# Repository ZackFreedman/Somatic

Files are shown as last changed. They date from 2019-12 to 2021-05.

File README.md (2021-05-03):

# Somatic
The Somatic is a wearable keyboard and mouse. It translates hand signs and motions into action, like the somatic component of a spell in Dungeons and Dragons.

See the project in action at https://www.youtube.com/watch?v=6raRftH9yxM!

**This project is defunct!!** The EM7180SFP is no longer in production, and I can't put any more effort into this project to design around it. Consider this a starting point only!

The Somatic project's priorities are:
* Control any wearable computer with a heads-up display
* Ready to use all day, instantly, with no Internet
* Doesn't cause fatigue or interfere with other tasks
* Fast enough to do a quick search in less than 10 seconds

The Somatic does not:
* Reproduce your hand in 3-D space
* Let you type on a virtual keyboard
* Use any cloud services at all

The project is still in a pretty rough state. If I revisit the project, the priorities are:
* Lay out and fab circuit board
* Make case smaller
* Replace on/off Hall sensors with continuous sensors

The Somatic project is MIT licensed, copyright 2019 Zack Freedman and Voidstar Lab.

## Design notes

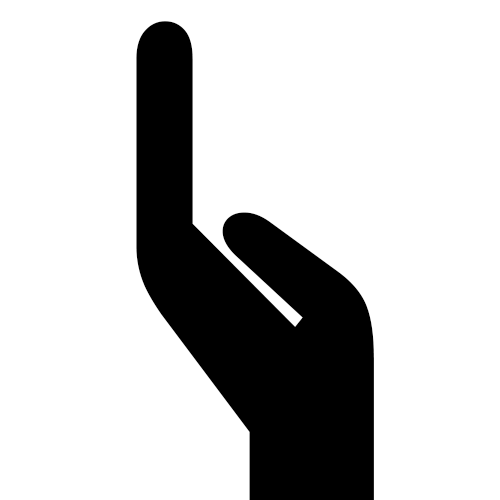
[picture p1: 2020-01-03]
Training Utility/somatictrainer/Hands/Unknown.png

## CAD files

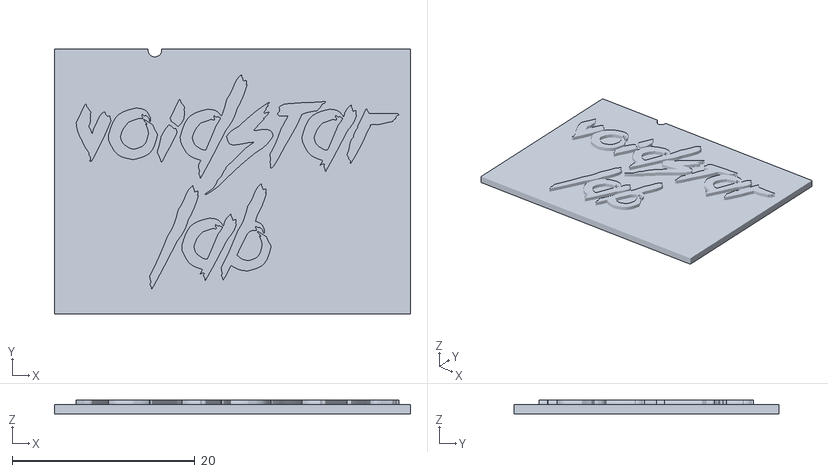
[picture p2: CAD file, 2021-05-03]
Models/STL's/Cosmetic Plate Top.stl
39.0 x 29.0 x 1.50

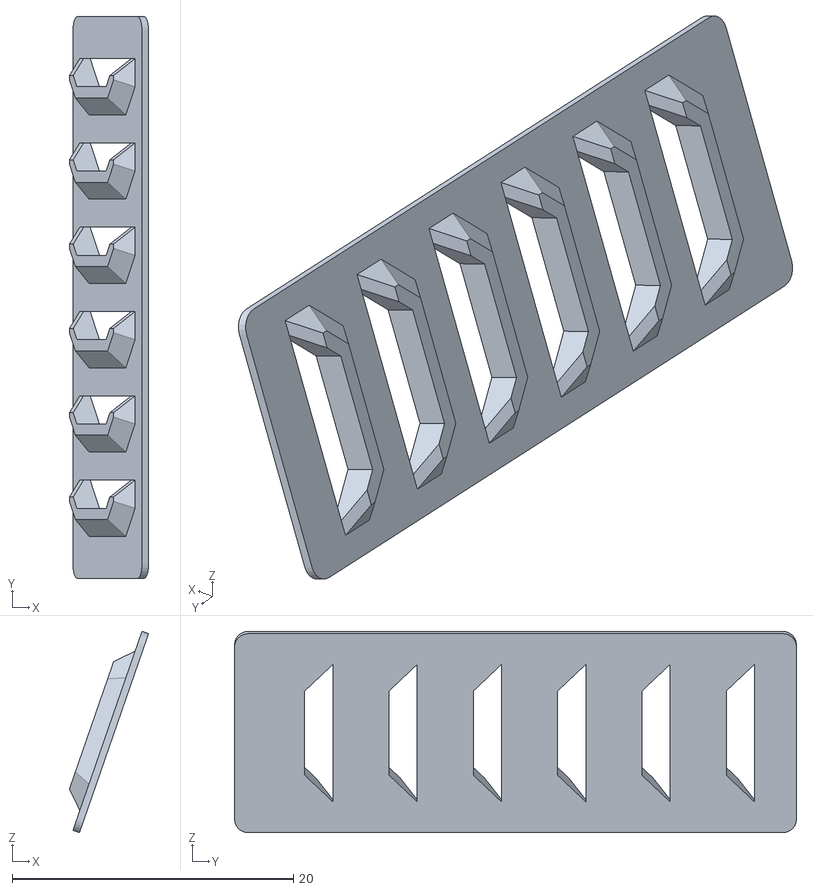
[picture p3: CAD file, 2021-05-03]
Models/STL's/Cosmetic Plate Side.stl
5.64 x 40.0 x 14.3

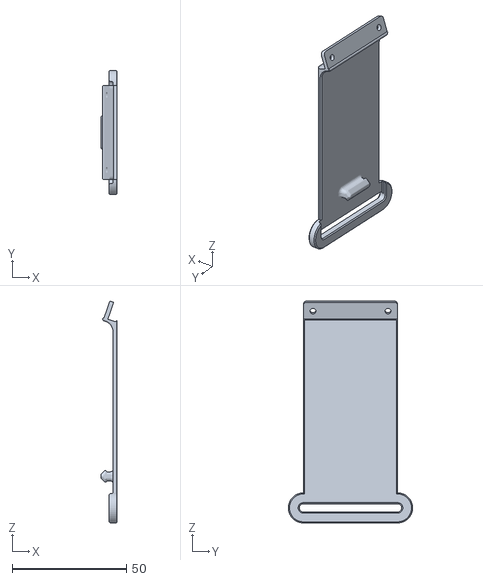
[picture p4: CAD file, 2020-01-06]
Models/STL's/Buckle Strap.stl
7.20 x 54.4 x 97.1

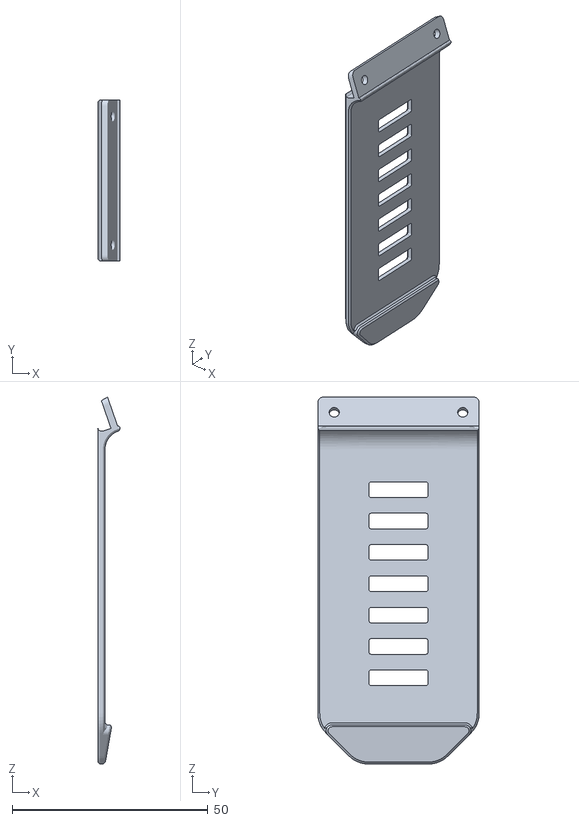
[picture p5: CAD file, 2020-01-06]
Models/STL's/Holey Strap.stl
5.67 x 41.2 x 93.7

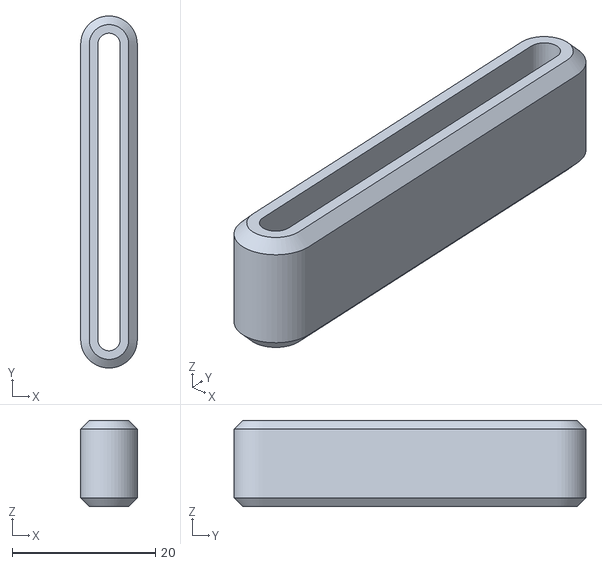
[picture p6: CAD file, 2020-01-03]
Models/STL's/Loop Brother.stl
7.90 x 49.1 x 12.0

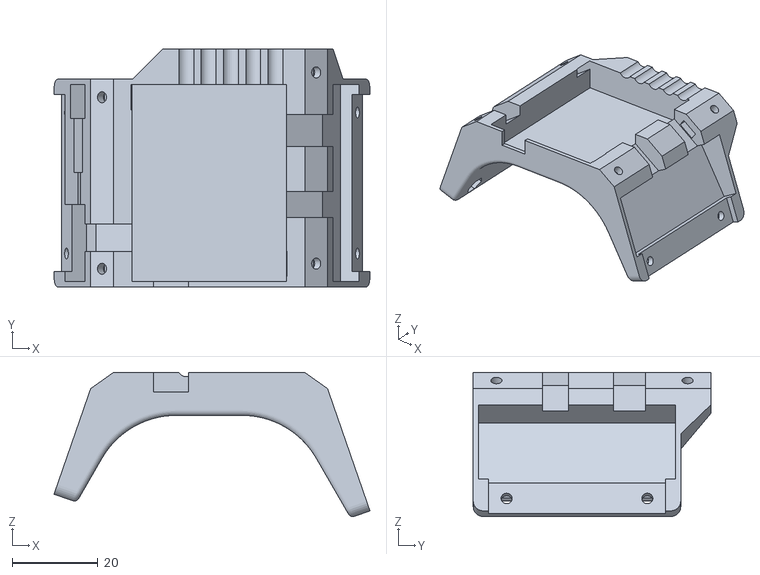
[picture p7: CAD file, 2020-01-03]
Models/STL's/Body.stl
73.7 x 55.4 x 33.6

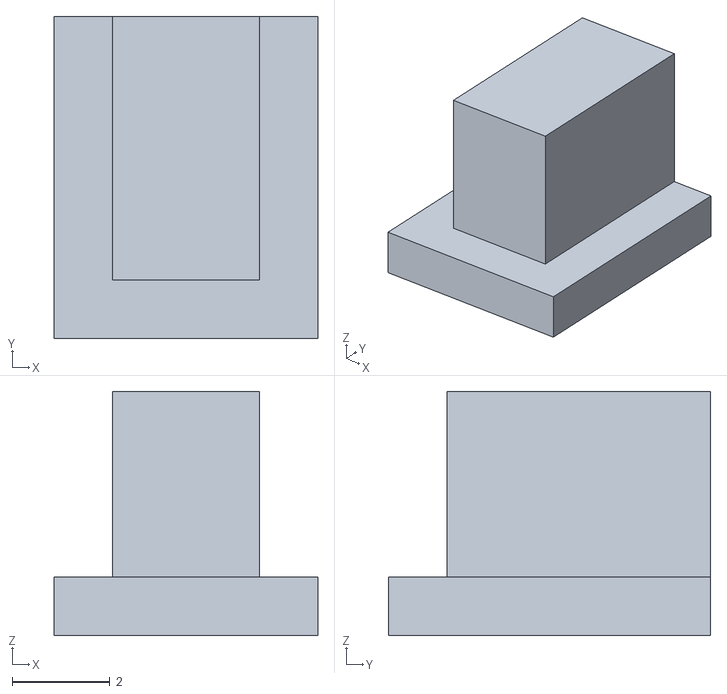
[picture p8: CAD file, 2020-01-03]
Models/STL's/Power Switch.stl
5.40 x 6.59 x 5.00

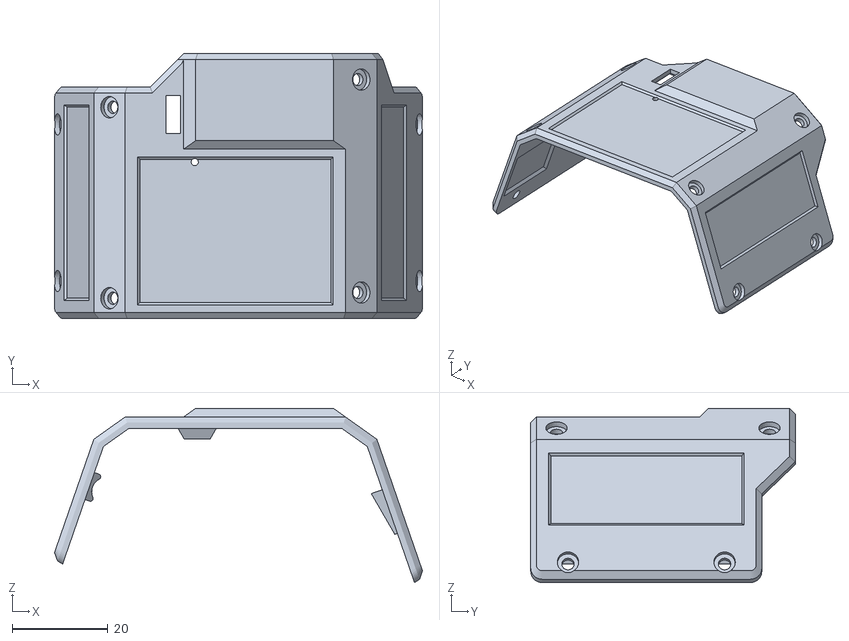
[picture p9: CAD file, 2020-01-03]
Models/STL's/Top Plate.stl
77.1 x 55.4 x 36.5

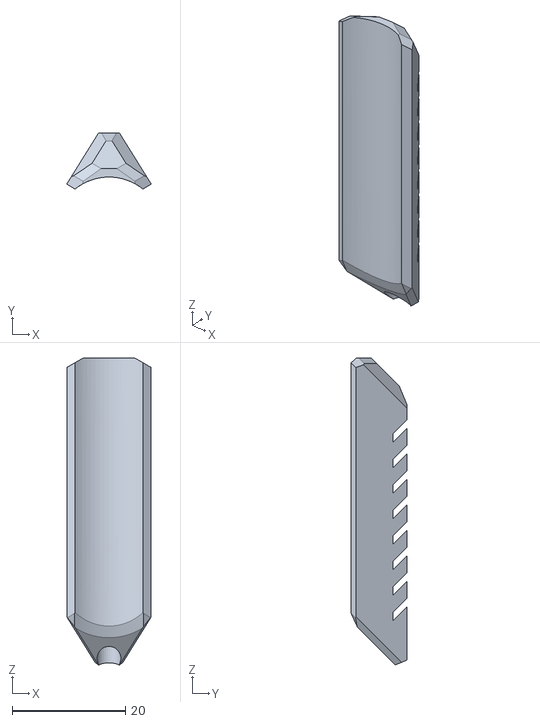
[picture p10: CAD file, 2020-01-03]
Models/STL's/Magnet Holder Long.stl
14.9 x 9.93 x 54.2

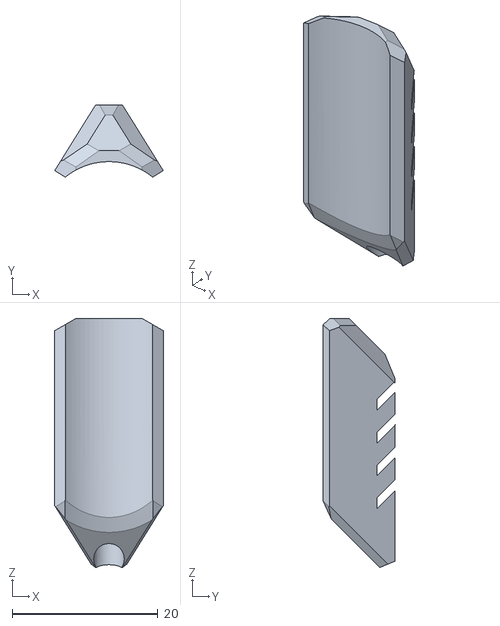
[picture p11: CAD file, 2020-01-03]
Models/STL's/Magnet Holder Short.stl
14.9 x 9.93 x 34.2

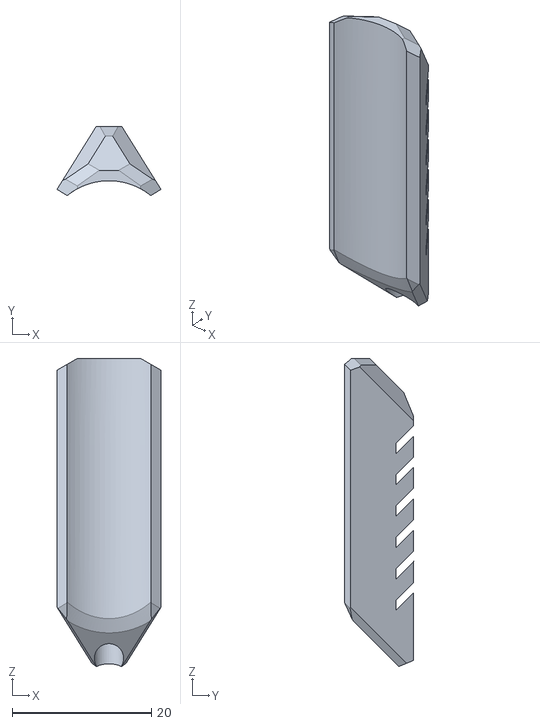
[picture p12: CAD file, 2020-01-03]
Models/STL's/Magnet Holder Medium.stl
14.9 x 9.93 x 44.2

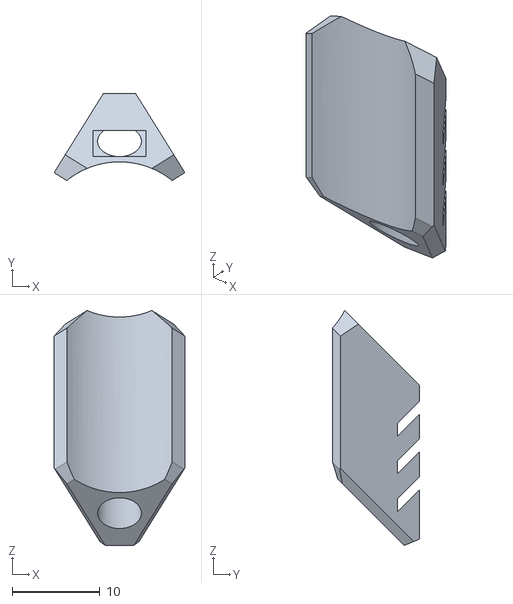
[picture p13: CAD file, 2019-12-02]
Models/STL's/Hall Holder.stl
14.9 x 9.93 x 26.8

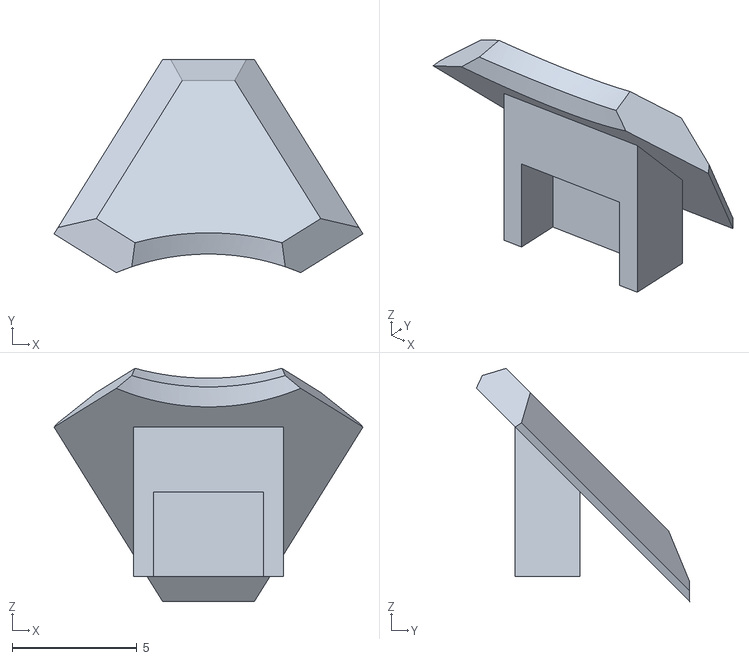
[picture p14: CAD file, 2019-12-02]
Models/STL's/Hall Cover.stl
12.4 x 8.55 x 9.35

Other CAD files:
Models/STL's/Nameplate.stl
Models/Somatic Finger Assembly.f3d
Models/Somatic IMU Holder.f3d
Models/Somatic Wristlet.f3d

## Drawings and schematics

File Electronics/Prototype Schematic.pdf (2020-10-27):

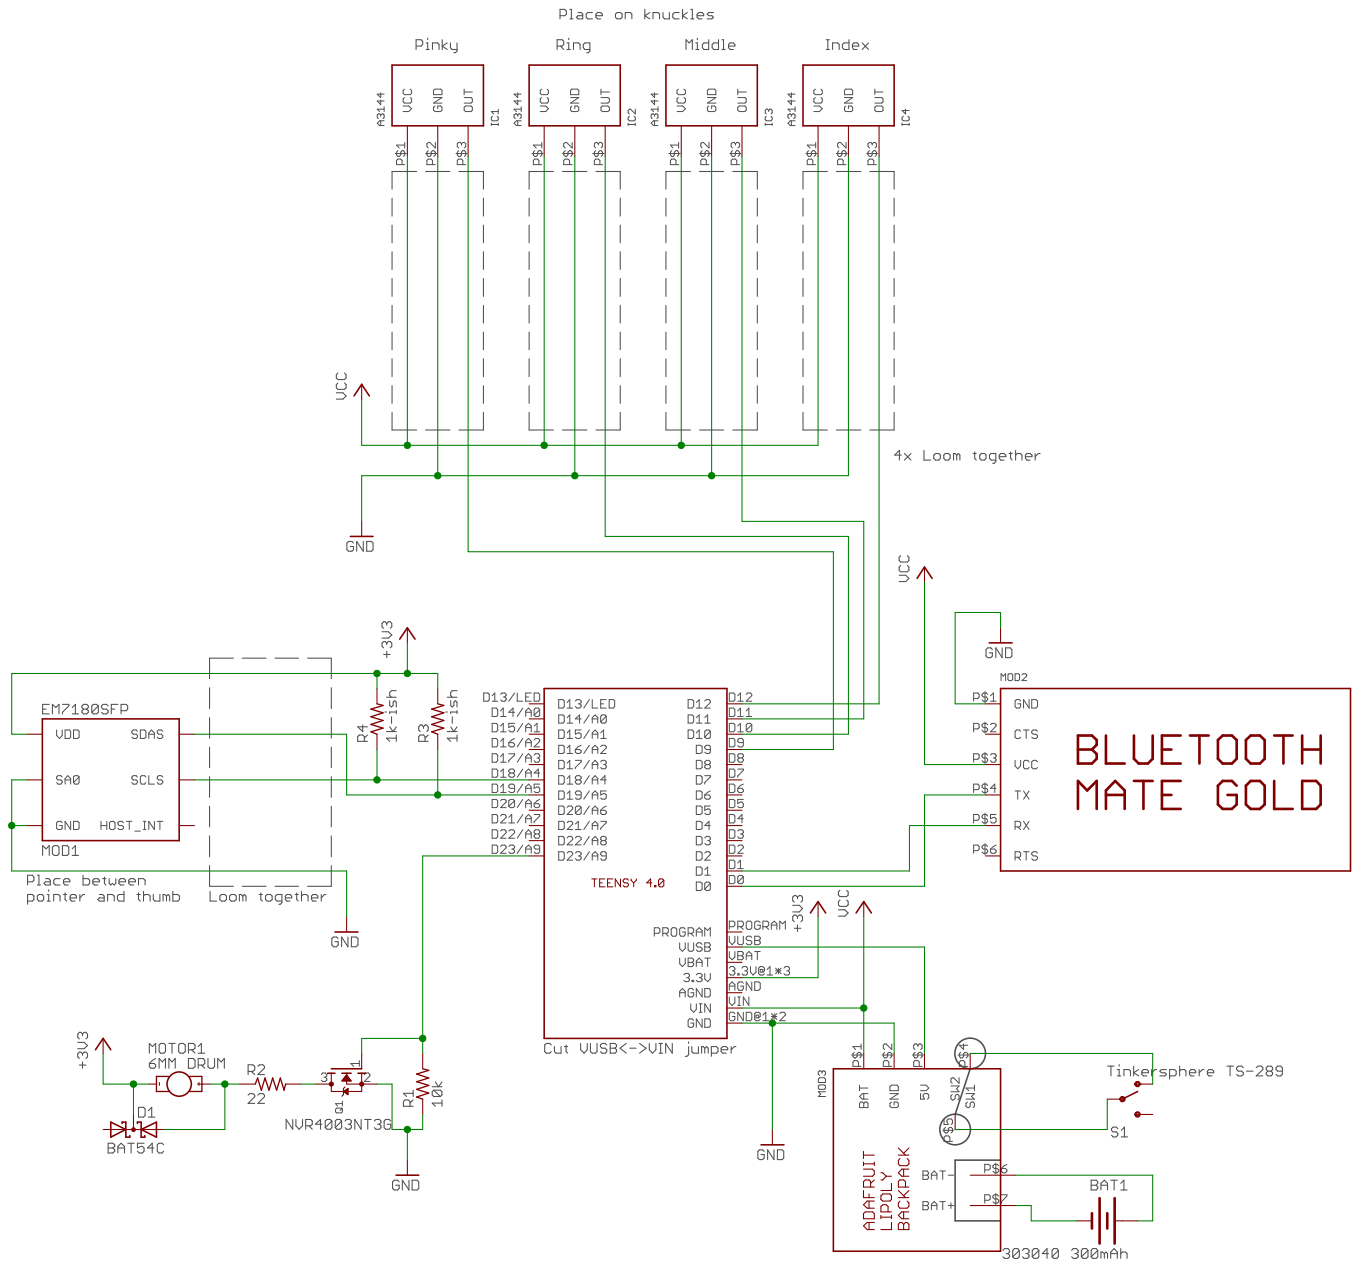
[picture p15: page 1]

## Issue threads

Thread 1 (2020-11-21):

Right handed?

DieKatzchen, 2020-11-21:
How possible would it be to simply mirror the training data and train a right-handed version?

ZackFreedman, 2020-11-21:
It shouldn’t be necessary. You draw the same letters whether you’re a lefty or a righty.
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

DieKatzchen, 2020-11-21:
Now that I'm thinking about it again, you are obviously right. So I would just mirror the relevant 3D printed parts and use the right glove instead of the left. Guess I have a new project for next weekend (This weekend is, obviously, already spoken for)

JerryGreen, 2020-12-18:
@DieKatzchen I'm pretty sure that requires more than a weekend. Let me guess, - you still didn't make this right-handed version? 😂

DieKatzchen, 2020-12-18:
I've actually been thinking I should make a display first. Been looking at various OLED screens and mirrors and such.

Closed 2020-11-22.

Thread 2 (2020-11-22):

Running on ESP32

DieKatzchen, 2020-11-22:
Running this on an esp32 should be doable, right? it would reduce the partslist since it could do the bluetooth keyboard and mouse itself, without needing the bluetooth mate.

[EDIT]Placing these here for future reference
https://github.com/T-vK/ESP32-BLE-Mouse
https://github.com/T-vK/ESP32-BLE-Keyboard
[/EDIT]

sudomain, 2020-11-28:
The teensy 4 used in the Somatic operates at 600 MHz while I've read esp32's can operate at 160MHz or 240MHz, but in the Somatic youtube video (at 6:25) Zach says he underclocks the teensy to 150MHz and it works fine. Something that'll probably be an issue is the 520KB of SRAM being inadequate. The teensy has 1024 KB and somewhere in the video he said it used 80% of the RAM.

DieKatzchen, 2020-11-29:
That's true, I forgot about that. The esp32 can use external ram, but at what point are we no longer simplifying things and just complicating them in me and exciting ways?

DieKatzchen, 2020-11-29:
Did some digging, there's an esp-wrover-b module with 8mib of ram already built in. So that can probably take care of it.

sudomain, 2020-11-29:
I'm not sure if you saw (and are referring to) the issue I opened (#3), but it'd be interesting to see the performance. External RAM modules will make the wrist area of the glove more bulky, but then again so will an additional bluetooth module for sending the raw data to an instance of TensorFlow Lite on Android.

DieKatzchen, 2020-11-30:
I made a preliminary attempt at changing this to use an esp32 and the blackketter/ESP32-BLE-Combo library. It compiles, and seems to communicate with the training app. Obviously I will need to build one to test it. If you want to have a look it's on my fork, I just pushed it.

sudomain, 2020-11-30:
Cool! I'm following your fork now. I think you could test it just with the IMU hooked up to the ESP32 since I think the hall sensors just act as push buttons.

DieKatzchen, 2020-12-05:
Pretty much. Payday is Monday, will buy just enough to test with.

Millimeter94, 2021-03-11:
@DieKatzchen: I just tried to compile your fork but i am missing these tree libraries:
BleCombo.h
elapsedMillis.h
analogWrite.h
Are those something special or can i use the first thing google spits out

DieKatzchen, 2021-03-11:
Whoops, my bad for forgetting to document my dependencies!

"BleCombo" library is from here: https://github.com/blackketter/ESP32-BLE-Combo
"ElapsedMillis" and "ESP32 AnalogWrite" are both available in the Library Manager.

ZackFreedman, 2021-04-12:
I appreciate your work in porting and forking the project, but please continue this discussion on the relevant repo.

Closed 2021-04-12.

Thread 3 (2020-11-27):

TensorFlow Lite on Android?

sudomain, 2020-11-27:
Hello. I'm only slightly familiar with the project (it's very cool by the way), but what do you think about moving the TensorFlow Lite model from the Teensy to [an android device](https://www.tensorflow.org/lite/guide/android)? The Teensy 4 chugs aways at 600 MHz, while many mid-grade Android devices are multicored and atleast double the clock speed (my already 3 year old LG clocks at 1.4 GHz). I realize that a phone's bluetooth can't just decide to act as HID device (without root?), so maybe use a process like this?:
1. use bluetooth to take signals from the Somatic,
2. send to TF lite on android for processing,
3. send the result back the the Somatic,
4. have the Somatic send the result as a HID device to whatever it is paired to

I know you said in the video that the Teensy works fine even when underclocked,  but if the tensorflow processing can be moved off device, maybe something smaller than the teensy could be used.

ZackFreedman, 2021-04-12:
Good idea, but I have no intention to continue working on this project. It's doable, but I'm not going to do it.

Closed 2021-04-12.

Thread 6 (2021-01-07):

IMU

jmonsalve15, 2021-01-07:
@ZackFreedman, I am working in this project. It is so cool, but the code is quite big and difficult to follow.

Can you give a bit or high level info about how the GUI expected the IMU data?

I would like get it working with a different IMU using quaternions...

TonMise, 2021-03-21:
Hey @jmonsalve15 any news?

I'm really interested in this project but, as you say, the code is quite big and difficult to follow.
I can't find the EM7180SFP anywhere and I was wondering if we could use the MPU-9250.

@ZackFreedman What do you think?

noob-master147, 2021-04-11:
same issue @TonMise EM7180SFP is not available anywhere, any alternatives @ZackFreedman ??

ZackFreedman, 2021-04-11:
The closest substitute is the Ultimate Sensor Fusion Solution board:
https://www.tindie.com/products/onehorse/ultimate-sensor-fusion-solution-mpu9250/

It's not a drop-in replacement - both the code and the IMU holder will
need modification.

Unfortunately, I'm not able to put any further work into this project.

------ Original Message ------
From: "Divyansh Khandelwal" ***@***.***>
To: "ZackFreedman/Somatic" ***@***.***>
Cc: "ZackFreedman" ***@***.***>; "Mention"
***@***.***>
Sent: 4/11/2021 12:43:14 PM
Subject: Re: [ZackFreedman/Somatic] IMU (#6)

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

Ovens-Syntax, 2022-04-27:
just realized this is from a year ago but might as well ask did anybody successfully implement the ultimate sensor fusion board or i guess make this thing work at all or not @TonMise @jmonsalve15 @noob-master147

Mike-Menci, 2023-01-28:
have a look here: https://www.emmicroelectronic.com/product/sensor-fusion/em7180sfp

Ovens-Syntax, 2023-02-12:
nice!

DarkButterfly85, 2023-02-14:
I've got the software side of things done, it looks promising, certainly giving me the output I expect, now to build the thing :-)

labviewadvocate, 2023-05-12:
> I've got the software side of things done, it looks promising, certainly giving me the output I expect, now to build the thing :-)

Any luck making it happen? Would love to see the new project.

Cryptorial0, 2024-07-20:
> I've got the software side of things done, it looks promising, certainly giving me the output I expect, now to build the thing :-)

any updates?

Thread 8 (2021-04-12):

STL variants of .f3d file

noob-master147, 2021-04-12:
## It would be really helpful if STL formats of these parts could be made available

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

ZackFreedman, 2021-04-12:
All of the STL's are in the STLs directory. There's nothing in the Fusion files that isn't already exported as STL's. I just designed the glove as three models instead of making a separate model for each part.

noob-master147, 2021-04-12:
got it
thanks a lot 💖

Closed 2021-04-12.

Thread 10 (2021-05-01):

Missing STL files?

Trixelit, 2021-05-01:
@ZackFreedman The instructable is telling me to print 'Cosmetic plate.stl' which isn't in the repository.

ZackFreedman, 2021-05-03:
I've added the missing files! The STL's are in millimeters.

------ Original Message ------
From: "Trixelit" ***@***.***>
To: "ZackFreedman/Somatic" ***@***.***>
Cc: "ZackFreedman" ***@***.***>; "Mention"
***@***.***>
Sent: 4/30/2021 10:20:18 PM
Subject: [ZackFreedman/Somatic] Missing STL files? (#10)

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

Trixelit, 2021-05-03:
Thank you!

Closed 2021-05-03.

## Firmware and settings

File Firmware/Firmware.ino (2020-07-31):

/*************
   Somatic data glove firmware
   by Zack Freedman of Voidstar Lab
   (c) Voidstar Lab 2019
   Somatic is licensed Creative Commons 4.0 Attribution Non-Commercial

   Uses code by Paul Joffressen, Kris Winer, Google, and the Arduino project

   Deploy to Teensy 4.0 at max clock speed
*/

#include <math.h>
#include <Wire.h>
#include <TensorFlowLite.h>
#include  "tensorflow/lite/experimental/micro/kernels/all_ops_resolver.h"
#include "tensorflow/lite/experimental/micro/micro_error_reporter.h"
#include "tensorflow/lite/experimental/micro/micro_interpreter.h"
#include "tensorflow/lite/experimental/micro/testing/micro_test.h"
#include "tensorflow/lite/schema/schema_generated.h"
#include "tensorflow/lite/version.h"
#include "model.h"

// The following dumb bullshit just lets us turn off serial debug
#define DEBUG
#define GET_MACRO(_1, _2, NAME, ...) NAME

byte me;

#ifdef DEBUG
#define debug_print_formatted(x, y) Serial.print(x,y)
#define debug_print_noformat(x) Serial.print(x)
#define debug_println_formatted(x, y) Serial.println(x, y)
#define debug_println_noformat(x) Serial.println(x)
#define debug_write(x) Serial.write(x)
#else
#define debug_print_formatted(x, y)
#define debug_print_noformat(x)
#define debug_println_formatted(x, y)
#define debug_println_noformat(x)
#define debug_write(x)
#endif

#define debug_print(...) GET_MACRO(__VA_ARGS__, debug_print_formatted, debug_print_noformat)(__VA_ARGS__)
#define debug_println(...) GET_MACRO(__VA_ARGS__, debug_println_formatted, debug_println_noformat)(__VA_ARGS__)
#define sanity(x) debug_println("Sanity " #x)
// End dumb debugging bullshit

// Keep this declaration here so I can use the debug macros in it
#include "imu.h"

#define training_mode
//#define hid_mode

//#define dont_actually_write
// #define debug_angular_velocity
//#define debug_gesture
#define debug_dump_bt_rx
//#define debug_tensorflow

#define bt Serial1
#define btResponseMaxLength 20
char btResponseBuffer[btResponseMaxLength];

// Globals, needed by TFLite
namespace {
tflite::ErrorReporter* error_reporter = nullptr;
const tflite::Model* model = nullptr;
tflite::MicroInterpreter* interpreter = nullptr;
TfLiteTensor* input = nullptr;
TfLiteTensor* output = nullptr;
int inference_count = 0;

// Create an area of memory to use for input, output, and intermediate arrays.
// Finding the minimum value for your model may require some trial and error.
constexpr int kTensorArenaSize = 4 * 1024;
uint8_t tensor_arena[kTensorArenaSize];
}  // namespace

unsigned long fingerDebounce = 100;

const byte btRtsPin = 2;
const byte vibePin = 23;
const byte fingerSwitchPins[] = {9, 10, 11, 12};

#define noHandSign 0
#define mouseHandSign 1
#define keebHandSign 10

bool lastFingerPositions[4];
byte handSign = noHandSign;
unsigned long lastFingerStableTimestamps[4] = {0};

float lastBearing[3];
float yaw;
float pitch;

const float velocityThresholdToBegin = 5. / 1000000.;  // In rad/microsecond
const float velocityThresholdToEnd = 1.5 / 1000000.;  // Also in rad/microsecond
const float mouseVelocityThreshold = 0.01 / 1000000.; // I don't plan on changing the units at this point
const int historyLength = 5;
float angularVelocityWindow[historyLength];

#define mouseScale 500.

float bearingAtLastBuzz[2];
const float distanceBetweenBuzzes = 12. / 180. * PI;
elapsedMillis timeSinceBuzzStarted;
unsigned long currentBuzzDuration;

#define interGestureLockout 200  // Milliseconds to ignore velocity after gesturing, to get your hand into the next position
//#define interGestureLockout 0
bool isDrawingGlyph;
elapsedMillis timeSinceLastGesture;
unsigned long lastTimestamp;

IMU imu = IMU();

elapsedMillis timeSinceLastDebugCommandChar;
#define commandLockout 10000

#define gestureConeAngle 2.0 / 3.0 * PI
float gestureBearingZero[2];
#define maxGestureLength 100
float gestureBuffer[100][2];  // These are all normalized to 0.0-1.0, where 0.5, 0.5 is the starting position
float gestureBufferYawMin;
float gestureBufferYawMax;
float gestureBufferPitchMin;
float gestureBufferPitchMax;
float processedGesture[50][2];
unsigned int gestureBufferLength;

bool isFrozen = false;
elapsedMillis timeSinceFreeze;
#define freezeTime 2000

void setup() {
  Serial.begin(115200);
  bt.begin(115200);

  delay(5000);
  #ifdef training_mode
  debug_println("Training mode");
  #endif

  #ifdef hid_mode
  debug_println("HID mode");
  #endif
  for (int i = 0; i < 3; i++) {
    delay(200);
    if (setUpBluetooth()) break;
  }

  analogWriteFrequency(vibePin, 93750);  // Set to high frequency so switching noise is inaudible
 
  pinMode(btRtsPin, INPUT);

  // Some butt-head didn't leave room for i2c pullups on the lil board.
  // Using adjacent pins as makeshift 3V3 sources :|
  pinMode(17, OUTPUT);
  digitalWrite(17, HIGH);
  pinMode(20, OUTPUT);
  digitalWrite(20, HIGH);

  pinMode(vibePin, OUTPUT);

  Wire.begin();
  Wire.setClock(400000);
  imu.setup();

  for (int i = 0; i < 4; i++) {
    pinMode(fingerSwitchPins[i], INPUT_PULLUP);
  }

  // The following wad-o-code is cribbed straight from the TFLite hello_world project
  static tflite::MicroErrorReporter micro_error_reporter;
  error_reporter = &micro_error_reporter;

  // Map the model into a usable data structure. This doesn't involve any
  // copying or parsing, it's a very lightweight operation.
  model = tflite::GetModel(modelBin);
  if (model->version() != TFLITE_SCHEMA_VERSION) {
    error_reporter->Report(
      "Model provided is schema version %d not equal "
      "to supported version %d.",
      model->version(), TFLITE_SCHEMA_VERSION);
    return;
  }

  // This pulls in all the operation implementations we need.
  // NOLINTNEXTLINE(runtime-global-variables)
  static tflite::ops::micro::AllOpsResolver resolver;

  // Build an interpreter to run the model with.
  static tflite::MicroInterpreter static_interpreter(
    model, resolver, tensor_arena, kTensorArenaSize, error_reporter);
  interpreter = &static_interpreter;

  // Allocate memory from the tensor_arena for the model's tensors.
  TfLiteStatus allocate_status = interpreter->AllocateTensors();
  if (allocate_status != kTfLiteOk) {
    error_reporter->Report("AllocateTensors() failed");
    return;
  }

  // Obtain pointers to the model's input and output tensors.
  input = interpreter->input(0);
  output = interpreter->output(0);

  debug_print("Input tensor size: ");
  debug_print(input->dims->size);
  debug_print(" Shape: (");
  for (int i = 0; i < 3; i++) {
    debug_print(input->dims->data[i]);
    if (i < 2) debug_print(", ");
  }
  debug_println(')');

  debug_print("Output tensor size: ");
  debug_print(output->dims->size);
  debug_print(" Shape: (");
  for (int i = 0; i < 3; i++) {
    debug_print(input->dims->data[i]);
    if (i < 2) debug_print(", ");
  }
  debug_println(')');

  // Keep track of how many inferences we have performed.
  inference_count = 0;

  debug_print("Gesture cone angle: ");
  debug_println(gestureConeAngle, 5);

  lastTimestamp = micros();
}

// TODO: Move non-sensor stuff out of sensor-dependent if block

void loop() {
  unsigned long timestamp = micros();
  float sampleRate = timestamp - lastTimestamp;

  if (timeSinceBuzzStarted > currentBuzzDuration) {
    analogWrite(vibePin, 0);
  }

  while (Serial.available()) {
    int incoming = Serial.read();
    //    Serial.write(incoming);
    bt.write(incoming);

    timeSinceLastDebugCommandChar = 0;
  }

  while (bt.available()) {
    if (bt.peek() == '>') {
      if (bt.available() >= 5
          && bt.read() == '>'
          && bt.read() == 'A'
          && bt.read() == 'T'
          && bt.read() == '\r'
          && bt.read() == '\n') {
        debug_println("Got AT - request to acknowledge");
        bt.print(">OK\n");
      }
      else break;
    }
    else {
#ifdef debug_dump_bt_rx
      if (timeSinceLastDebugCommandChar < commandLockout)
        timeSinceLastDebugCommandChar = 0;
      Serial.write(bt.read());
#endif
    }
  }

  // TODO: Handle %CONNECT,5800E382649E,0 and %DISCONNECT messages from bt

  if (imu.poll() & 0x04) {  // Only send data when we have new AHRS
    yaw = imu.Quat[0] * -1;
    pitch = imu.Quat[1];

    float theta = 0;

    theta = asin(norm(lastBearing[0], lastBearing[1], yaw, pitch));
    float angularVelocity = theta / sampleRate;

#ifdef debug_angular_velocity
    debug_print("Theta: ");
    debug_println(theta);
    debug_print("Angular velocity (per sec): ");
    debug_println(angularVelocity * 1000000.);
#endif

    float angularVelocityAverage = angularVelocity;

    for (int i = historyLength - 2; i >= 0; i--) {
      angularVelocityAverage += angularVelocityWindow[i];
      angularVelocityWindow[i + 1] = angularVelocityWindow[i];
    }

    angularVelocityWindow[0] = angularVelocity;

    angularVelocityAverage /= historyLength;

    for (int i = 0; i < 4; i++) {
      bool fingerPosition = digitalRead(fingerSwitchPins[i]);
      if (fingerPosition == lastFingerPositions[i]) {
        lastFingerStableTimestamps[i] = millis();
      }
      else if (millis() - lastFingerStableTimestamps[i] >= fingerDebounce) {
        lastFingerPositions[i] = fingerPosition;
        lastFingerStableTimestamps[i] = millis();
      }
    }

    // Keyboard stuff
    bool handIsMovingFastEnoughToDraw = false;

    if (timeSinceLastGesture < interGestureLockout)
      handIsMovingFastEnoughToDraw = false;
    else if ((isDrawingGlyph && angularVelocityAverage >= velocityThresholdToEnd)
             //        || (!isDrawingGlyph && angularVelocityAverage >= velocityThresholdToBegin)) {
             || (!isDrawingGlyph && angularVelocity >= velocityThresholdToBegin)) {  // Don't use average - we want a snappier start
      handIsMovingFastEnoughToDraw = true;
    }

    if (lastFingerPositions[0] && lastFingerPositions[1] && lastFingerPositions[2] && !lastFingerPositions[3]) {
      handSign = keebHandSign;
    }
    else if (lastFingerPositions[0] && lastFingerPositions[1] && !lastFingerPositions[2] && !lastFingerPositions[3]) {
      handSign = mouseHandSign;
    }
    else
      handSign = noHandSign;

    if (handIsMovingFastEnoughToDraw) {
      if (handSign == keebHandSign) {
        if (!isDrawingGlyph) {
          buzzFor(250, 15);
          bearingAtLastBuzz[0] = yaw;
          bearingAtLastBuzz[1] = pitch;
          gestureBufferLength = 0;
          debug_print("Started gesturing after ");
          debug_print(timeSinceLastGesture);
          debug_println(" ms");
        }
        isDrawingGlyph = true;
      }
    }
    else {
      if (isDrawingGlyph)
        debug_println("Stopped gesturing");
      isDrawingGlyph = false;
    }

    // Record and process gestures! This is the business end!
    char winningGlyph = 0x00;
    float topScore = 0.;

    if (isDrawingGlyph) {
      if (gestureBufferLength < maxGestureLength) {
        if (gestureBufferLength == 0) {
          gestureBearingZero[0] = yaw;
          gestureBearingZero[1] = pitch;
          gestureBuffer[0][0] = gestureBufferYawMin = gestureBufferYawMax = 0.5;
          gestureBuffer[0][1] = gestureBufferPitchMin = gestureBufferPitchMax = 0.5;

#ifdef debug_gesture
          debug_println("Starting gesture!");
          debug_print("Bearing zero is (");
          debug_print(gestureBearingZero[0], 3);
          debug_print(", ");
          debug_print(gestureBearingZero[1], 3);
          debug_println(')');
#endif
        }
        else {
#ifdef debug_gesture
          debug_print("Raw bearing: (");
          debug_print(yaw, 3);
          debug_print(", ");
          debug_print(pitch, 3);
          debug_println(')');
#endif

          float processedYaw = wrappedDelta(gestureBearingZero[0], yaw);
          float processedPitch = wrappedDelta(gestureBearingZero[1], pitch);

          processedYaw = constrain(processedYaw, -0.5 * gestureConeAngle, 0.5 * gestureConeAngle);
          processedPitch = constrain(processedPitch, -0.5 * gestureConeAngle, 0.5 * gestureConeAngle);

          processedYaw /= gestureConeAngle;
          processedPitch /= gestureConeAngle;

          processedYaw += 0.5;
          processedPitch += 0.5;

          gestureBufferYawMin = min(gestureBufferYawMin, processedYaw);
          gestureBufferYawMax = max(gestureBufferYawMax, processedYaw);
          gestureBufferPitchMin = min(gestureBufferPitchMin, processedPitch);
          gestureBufferPitchMax = max(gestureBufferPitchMax, processedPitch);

          gestureBuffer[gestureBufferLength][0] = processedYaw;
          gestureBuffer[gestureBufferLength][1] = processedPitch;

#ifdef debug_gesture
          debug_print("Processed bearing: (");
          debug_print(processedYaw, 3);
          debug_print(", ");
          debug_print(processedPitch, 3);
          debug_println(')');
#endif
        }

        gestureBufferLength++;
      }
#ifdef debug_gesture
      else {
        debug_println("This gesture is too damn long!");
      }
#endif
    }
    else if (gestureBufferLength > 0) {
      timeSinceLastGesture = 0;
      buzzFor(250, 40);

#ifdef debug_gesture
      debug_print("Gesture over - ");
      debug_print(gestureBufferLength);
      debug_println(" points");
#endif

      processBearings(gestureBuffer, gestureBufferLength,
                      gestureBufferYawMin, gestureBufferYawMax, gestureBufferPitchMin, gestureBufferPitchMax,
                      processedGesture, 50);
#ifdef debug_gesture
      for (int i = 0; i < 50; i++) {
        debug_print("Point ");
        debug_print(i);
        debug_print(": (");
        debug_print(processedGesture[i][0]);
        debug_print(", ");
        debug_print(processedGesture[i][1]);
        debug_println(')');
      }
#endif

#ifdef debug_tensorflow
      unsigned long tfBenchmark = micros();
#endif

      // Machine learning hijinks follows
      for (int i = 0; i < 100; i++) {
        input->data.f[i] = processedGesture[i / 2][i % 2];
      }

      TfLiteStatus invokeStatus = interpreter->Invoke();

      if (invokeStatus != kTfLiteOk) {
        error_reporter->Report("Failed to invoke\n");
      }
      else {
        for (int i = 0; i <= charCount; i++) {
          float score = output->data.f[i];
          if (score > topScore) {
            winningGlyph = charMap[i];
            topScore = score;
          }

#ifdef debug_tensorflow
          debug_print("Output tensor ");
          debug_print(i);
          debug_print(" (");

          if (charMap[i] >= ' ')
            debug_print(char(charMap[i]));
          else {
            debug_print("0x");
            debug_print(charMap[i], HEX);
          }

          debug_print("): ");
          debug_println(score, 4);
#endif
        }

#ifdef debug_tensorflow
        debug_print("Inference took ");
        debug_print(micros() - tfBenchmark);
        debug_println("us");
#endif

        for (int i = 0; i < 50; i++) {
          if (winningGlyph >= ' ')
            debug_print(winningGlyph);
          else {
            debug_print("0x");
            debug_print(winningGlyph, HEX);
            debug_print(' ');
          }
        }
        debug_println();
      }

      gestureBufferLength = 0;
    }  // gestureBufferLength > 0

    if (timeSinceBuzzStarted >= 80
        && isDrawingGlyph
        && norm(bearingAtLastBuzz[0], bearingAtLastBuzz[1], yaw, pitch) >= distanceBetweenBuzzes) {
      buzzFor(250, 15);
      bearingAtLastBuzz[0] = yaw;
      bearingAtLastBuzz[1] = pitch;
    }

    if (timeSinceLastDebugCommandChar >= commandLockout) {
      if (!digitalRead(btRtsPin)) {
#ifdef training_mode
        //   Packet format:
        //   >[./|],[./|],[./|],[./|],[float h],[float p],[float r],[float accel x],[accel y],[accel z],[us since last sample]
        char outgoingPacket[100] = {0};
        outgoingPacket[0] = '>';

        if (lastFingerPositions[0]) outgoingPacket[1] = '.';
        else outgoingPacket[1] = '|';
        outgoingPacket[2] = ',';

        if (lastFingerPositions[1]) outgoingPacket[3] = '.';
        else outgoingPacket[3] = '|';
        outgoingPacket[4] = ',';

        if (lastFingerPositions[2]) outgoingPacket[5] = '.';
        else outgoingPacket[5] = '|';
        outgoingPacket[6] = ',';

        if (lastFingerPositions[3]) outgoingPacket[7] = '.';
        else outgoingPacket[7] = '|';
        outgoingPacket[8] = ',';

        dtostrf(yaw, 6, 4, &outgoingPacket[strlen(outgoingPacket)]);
        outgoingPacket[strlen(outgoingPacket)] = ',';

        dtostrf(pitch, 6, 4, &outgoingPacket[strlen(outgoingPacket)]);
        outgoingPacket[strlen(outgoingPacket)] = ',';

        dtostrf(imu.Quat[2], 6, 4, &outgoingPacket[strlen(outgoingPacket)]);
        outgoingPacket[strlen(outgoingPacket)] = ',';

        dtostrf(imu.ax, 7, 4, &outgoingPacket[strlen(outgoingPacket)]);
        outgoingPacket[strlen(outgoingPacket)] = ',';

        dtostrf(imu.ay, 7, 4, &outgoingPacket[strlen(outgoingPacket)]);
        outgoingPacket[strlen(outgoingPacket)] = ',';

        dtostrf(imu.az, 7, 4, &outgoingPacket[strlen(outgoingPacket)]);
        outgoingPacket[strlen(outgoingPacket)] = ',';

        itoa(sampleRate, &outgoingPacket[strlen(outgoingPacket)], 10);
        outgoingPacket[strlen(outgoingPacket)] = '\n';

        bt.write(outgoingPacket, strlen(outgoingPacket));
#endif  // ifdef training_mode

#ifdef hid_mode
        byte packetLength = 0;

        if (winningGlyph == 0x00) {
          // Mouse stuff
          if (handSign == mouseHandSign && angularVelocityAverage >= mouseVelocityThreshold) {
            int xStop = wrappedDelta(lastBearing[0], yaw) * mouseScale;
            int yStop = wrappedDelta(lastBearing[1], pitch) * mouseScale;

            if (xStop != 0 || yStop != 0) {
              debug_print("Moving mouse ");
              debug_print(xStop);
              debug_print(" units right and ");
              debug_print(yStop);
              debug_println(" units up");

              // Raw mouse report format. See RN42 HID User Guide, or really the BT spec itself
              byte buf[] = {0xfd, 0x05, 0x02, 0x00, char(xStop), char(yStop), 0x00};
              bt.write(buf, 7);
            }
          }
        }
        else {
          bt.print(winningGlyph);
          debug_print("Typing ");
          debug_println(char(winningGlyph));
        }
#endif  // ifdef hid_mode

        if (isFrozen) {
          debug_println("Back to normal");
          isFrozen = false;
        }
      }
      else {
        if (!isFrozen) {
          debug_println("BOO! RTS! Can't send");
          timeSinceFreeze = 0;
          isFrozen = true;
        }
        else {
          if (timeSinceFreeze >= freezeTime) {
            debug_println("Kicking the module");
            bt.print('\n');
            timeSinceFreeze = 0;
          }
        }
      }
    }

    lastTimestamp = timestamp;
    lastBearing[0] = yaw;
    lastBearing[1] = pitch;
  }
}

void quaternionMultiply(float* q1, float* q2, float* out) {
  out[0] =  q1[0] * q2[3] + q1[1] * q2[2] - q1[2] * q2[1] + q1[3] * q2[0];
  out[1] = -q1[0] * q2[2] + q1[1] * q2[3] + q1[2] * q2[0] + q1[3] * q2[1];
  out[2] =  q1[0] * q2[1] - q1[1] * q2[0] + q1[2] * q2[3] + q1[3] * q2[2];
  out[3] = -q1[0] * q2[0] - q1[1] * q2[1] - q1[2] * q2[2] + q1[3] * q2[3];
}

bool setUpBluetooth() {
  // Note that this will ALWAYS FAIL when the module is connected in PAIR mode and the CPU alone is reset.
  // I did that for convenience, to use the module's built-in autoconnect.
  // TODO: Connect programmatically

  debug_println("Configuring BT. Emptying buffer...");
  while (bt.available()) bt.read();  // %REBOOT\r message in particular may jam up the works

  debug_println("Entering command mode...");
  bt.print("$$$");
  if (!btExpect("CMD", 200)) {
    debug_println("Failed to enter command mode");
    bt.setTimeout(20);
    return false;
  }

  debug_println("Setting pairing mode");
  bt.println("SM,6");
  if (!btExpect("AOK", 200)) return false;

  // TODO: Check if a setting is already correct, spare the EEPROM some pain

#ifdef training_mode
  debug_println("Switching to SPP mode");
  bt.println("S~,0");
  if (!btExpect("AOK", 200)) return false;
#endif  // training_mode
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

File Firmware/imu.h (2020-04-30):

#ifndef IMU_h_
#define IMU_h_

//#include <i2c_t3.h>
//#include <Wire.h>
#include "IMU_data.h"

class IMU {
  private:
    // HPR output
    const byte enuOutput = 0b00100000;
    const byte sixAxisOutput = 0b00001000;
    const byte nineAxisOutput = 0b00000000;
    const byte hprOutput = 0b00000100;
    const byte quaternionOutput = 0b00000000;
    const byte rawDataOutput = 0b00000010;
    const byte calibratedDataOutput = 0b00000000;
    const byte standbyEnabled = 0b00000001;
    const byte standbyDisabled = 0b00000000;
    const byte algorithmControlDefaults = hprOutput + calibratedDataOutput + standbyDisabled + sixAxisOutput;
    //    const byte algorithmControlDefaults = 0b00000100;

    struct accelerometerCalibrationData
    {
      int16_t accZero_max[3];
      int16_t accZero_min[3];
    };

    struct warmStartData
    {
      uint8_t Sen_param[35][4];
    };

    // I2C EEPROM wrappers. Needs special methods because addresses are two bytes.
    byte M24512DFMreadByte(uint8_t device_address, uint8_t data_address1, uint8_t data_address2);
    void M24512DFMreadBytes(uint8_t device_address, uint8_t data_address1, uint8_t data_address2, uint8_t count, uint8_t * dest);

    byte readByte(uint8_t, uint8_t);
    void readBytes(uint8_t, uint8_t, uint8_t, uint8_t*);
    void writeByte(uint8_t, uint8_t, uint8_t);

    float uint32_reg_to_float(uint8_t*);
    void float_to_bytes(float, uint8_t*);

    void enterPassthrough();
    void leavePassthrough();

    accelerometerCalibrationData loadAccelerometerCalibrationData();
    void calibrateAccelerometer(accelerometerCalibrationData global_conf);

    warmStartData loadWarmStartData();
    void warmStart(warmStartData WS_params);

    void EM7180_set_gyro_FS(uint16_t);
    void EM7180_set_mag_acc_FS(uint16_t, uint16_t);
    void EM7180_set_integer_param(uint8_t, uint32_t);
    void EM7180_set_float_param(uint8_t, float);

    void readSENtralQuatData(float*);
    void readSENtralAccelData(int16_t*);
    void readSENtralGyroData(int16_t*);
    void readSENtralMagData(int16_t*);

    byte param[4];

  public:
    IMU() {}

    void setup();
    uint8_t poll();
    void sleep();
    void wake();

    byte algorithmStatus;
    bool faulty;

    float ax, ay, az;
    float gx, gy, gz;
    float mx, my, mz;
    float Quat[4];
    float Yaw, Pitch, Roll;
};

byte IMU::readByte(uint8_t address, uint8_t subAddress)
{
  uint8_t data; // `data` will store the register data
  Wire.beginTransmission(address);         // Initialize the Tx buffer
  Wire.write(subAddress);                   // Put slave register address in Tx buffer
  //  Wire.endTransmission(I2C_NOSTOP);        // Send the Tx buffer, but send a restart to keep connection alive
  Wire.endTransmission(false);             // Send the Tx buffer, but send a restart to keep connection alive
  //  Wire.requestFrom(address, 1);  // Read one byte from slave register address
  Wire.requestFrom(address, (size_t) 1);   // Read one byte from slave register address
  data = Wire.read();                      // Fill Rx buffer with result
  return data;                             // Return data read from slave register
}

void IMU::readBytes(uint8_t address, uint8_t subAddress, uint8_t count, uint8_t * dest)
{
  Wire.beginTransmission(address);   // Initialize the Tx buffer
  Wire.write(subAddress);            // Put slave register address in Tx buffer
  //  Wire.endTransmission(I2C_NOSTOP);  // Send the Tx buffer, but send a restart to keep connection alive
  Wire.endTransmission(false);       // Send the Tx buffer, but send a restart to keep connection alive
  uint8_t i = 0;
  //        Wire.requestFrom(address, count);  // Read bytes from slave register address
  Wire.requestFrom(address, (size_t) count);  // Read bytes from slave register address
  while (Wire.available()) {
    dest[i++] = Wire.read();
  }         // Put read results in the Rx buffer
}

void IMU::writeByte(uint8_t address, uint8_t subAddress, uint8_t data)
{
  Wire.beginTransmission(address);  // Initialize the Tx buffer
  Wire.write(subAddress);           // Put slave register address in Tx buffer
  Wire.write(data);                 // Put data in Tx buffer
  Wire.endTransmission();           // Send the Tx buffer
}

uint8_t IMU::M24512DFMreadByte(uint8_t device_address, uint8_t data_address1, uint8_t data_address2)
{
  uint8_t data; // `data` will store the register data
  Wire.beginTransmission(device_address);         // Initialize the Tx buffer
  Wire.write(data_address1);                      // Put slave register address in Tx buffer
  Wire.write(data_address2);                      // Put slave register address in Tx buffer
  //  Wire.endTransmission(I2C_NOSTOP);               // Send the Tx buffer, but send a restart to keep connection alive
  Wire.endTransmission(false);
  Wire.requestFrom(device_address, (size_t)1);   // Read one byte from slave register address
  data = Wire.read();                             // Fill Rx buffer with result
  return data;                                    // Return data read from slave register
}

void IMU::M24512DFMreadBytes(uint8_t device_address, uint8_t data_address1, uint8_t data_address2, uint8_t count, uint8_t * dest)
{
  Wire.beginTransmission(device_address);            // Initialize the Tx buffer
  Wire.write(data_address1);                         // Put slave register address in Tx buffer
  Wire.write(data_address2);                         // Put slave register address in Tx buffer
  //  Wire.endTransmission(I2C_NOSTOP);                  // Send the Tx buffer, but send a restart to keep connection alive
  Wire.endTransmission(false);
  uint8_t i = 0;
  Wire.requestFrom(device_address, (size_t)count);  // Read bytes from slave register address
  while (Wire.available())
  {
    dest[i++] = Wire.read();
  }                                                   // Put read results in the Rx buffer
}

void IMU::enterPassthrough() {
  uint8_t statusByte = 0;

  // First put SENtral in standby mode
  writeByte(EM7180_ADDRESS, EM7180_AlgorithmControl, 0x01);
  delay(5);

  // Place SENtral in pass-through mode
  writeByte(EM7180_ADDRESS, EM7180_PassThruControl, 0x01);
  delay(5);
  statusByte = readByte(EM7180_ADDRESS, EM7180_PassThruStatus);
  while (!(statusByte & 0x01))
  {
    statusByte = readByte(EM7180_ADDRESS, EM7180_PassThruStatus);
    delay(5);
  }
}
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

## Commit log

2020-01-03 Added design files for sensor holders
    [Somatic Finger Assembly.f3d, Somatic IMU Holder.f3d]
2020-01-03 Improved wristlet
    More comfortable straps, better switch placement, and minor cleanup
    [Somatic Wristlet.f3d]
2020-01-03 Switched IMU from HPR to quaternion output
2020-01-03 Small improvements to fingers
    Added magnet holder STL's
    Moved first notch closer to end
    Improved parametric behavior
    [Magnet Holder Long.stl, Magnet Holder Medium.stl, Magnet Holder Short.stl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]
2020-01-03 Improved models
    Moved switch around
    Tightened up vibe holder
    Added PGM hole
    [Body.stl, Loop Brother.stl, Nameplate.stl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]
2020-01-03 Added schematic/wiring diagram
    [Prototype Schematic.sch]
2020-01-06 Improved strap
    [Buckle Strap.stl, Holey Strap.stl]
2020-01-17 Added gesture visualization, fixed zeroing incoming orientations
    [app.py]
2020-01-17 Added vibration feedback for gestures
    Vibrates lightly when keyboard gesture is active
    Vibrates more strongly while drawing
    [Firmware.ino]
2020-01-19 Bug fixes for saving, loading, glyph and gesture pickers
    [app.py, gestures.py]
2020-04-30 Refactored firmware and training util to use AHRS instead of quats. Also acceleration is recorded for ML use
    I think something's wrong with the fusion algorithm that makes the quat output janky
    Or I suck at math.
    Either way, works better now
    [Firmware.ino, app.py, gestures.py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]
2020-04-30 Added some missing files
    [sandbox.py, util.py]
2020-05-01 Experimenting with omitting accelerometer data
2020-05-02 Removed acceleration and time, added raw data archiving
    Removed acceleration and time-delta from data structures and processing -
    it made things hard and isn't necessary for accuracy.
    Just in case, all incoming data is saved, unmodified, with the gesture :)
2020-05-02 Implemented same angular-velocity calculation on glove and software
2020-05-03 Example picker is no longer re-created when adding a new example
    [app.py]
2020-05-03 UX improvements in training utility
    - Example picker no longer scrolls when mouse is over glyph picker
    - Automatically reopens training file and reconnects to glove
    - Bugfix: Active serial port's menu entry not checked
    [Firmware.ino, app.py]
2020-05-08 Bugfixes and improvements
    Improved recording stability, fixed irksome UI quirks
    [Firmware.ino, app.py, util.py]
2020-05-10 Bugfixes, debugging strings, etc to develop mirrored processing on glove
    [app.py, gestures.py, util.py]
2020-05-14 Added train-by-sentence and switched from JSON to pickle for dataset
2020-10-27 Added PDF Schematic
    Also added part name for Q1
    [Prototype Schematic.sch]
2021-05-03 Added missing files
    Replaced some files that I didn't commit the first time due to oversight
    [Cosmetic Plate Side.stl, Cosmetic Plate Top.stl]
